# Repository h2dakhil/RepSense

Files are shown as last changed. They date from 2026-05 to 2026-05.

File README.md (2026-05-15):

# Wrist Fitness Tracker — Custom PCB

A wrist-mounted, watch-form wearable that detects and counts gym exercise reps in real time using an IMU and sensor fusion. Built around a circular 42 mm custom PCB designed for low power, low cost, and size-constrained wearable use.

Inspired by the Apple Watch workout detection feature but built from scratch — custom hardware, custom firmware, no cloud dependency.

---

## Overview

The device sits on the wrist like a watch. It reads 6-axis motion data from an IMU, runs an Extended Kalman Filter (EKF) to fuse accelerometer and gyroscope data into a clean orientation estimate, and uses that to detect and count repetitions for exercises including:

- Bicep curl
- Shoulder press
- Bench press
- Lateral raise
- Squat
- Deadlift
- Overhead press

Rep count and exercise type are displayed in real time on a small OLED screen. The entire signal processing pipeline runs on-device with no wireless transmission required in v1.

---

## Hardware

### System block diagram
Screenshot 2026-05-14 at 12 40 06 PM

### MCU — nRF52840 QIAA QFN73

Nordic's nRF52840 was selected because it satisfies every constraint in a single chip with no external LDO required:

- Cortex-M4F at 64 MHz with hardware floating point — needed for EKF math
- Native USB (D+/D−) — drag-and-drop UF2 firmware flashing, no UART bridge chip
- BLE 5.0 built in — phone integration ready for v2 with no extra hardware
- Internal DC-DC converter (DCDCEN0) — steps VDDH down to 3.3V internally, powers entire board via EXTSUPPLY rail
- 1.5 µA deep sleep with wake-on-interrupt — critical for wearable battery life
- VDDH accepts up to 5.5V — direct PMIC output connection, no external LDO needed
- Same chip as the Seeed XIAO nRF52840 Sense used for firmware feasibility validation

**Circuit configuration:** Nordic Config 4 (High Voltage mode, DCDCEN0 enabled, USB enabled, NFC disabled). The PMIC SYS output feeds VDDH directly. The chip's internal REG0 DC-DC produces a stable 3.3V on VDD which is exposed as the board's entire 3.3V supply rail via EXTSUPPLY. One 10 µH inductor on DCCH is the only passive required for this configuration.

**Programming:** First-time bootloader flash via SWD using a J-Link EDU Mini and Tag-Connect TC2030-IDC-NL pads on the PCB. After the Adafruit UF2 bootloader is installed, all subsequent firmware updates are drag-and-drop `.uf2` over USB — identical to the Seeed dev board experience.

**Package selection:** QFN48 was considered and rejected. The QFN48 does not expose D+, D−, or VBUS — USB is physically absent. QFN73 is required. The 1 mm size difference per side is irrelevant at 42 mm PCB diameter.

### IMU — LSM6DSVTR

ST's LSM6DSV was selected for its onboard sensor fusion engine and FSM (Finite State Machine) which offload motion processing from the MCU:

- 6-axis: 3-axis accelerometer (±2 to ±16 g) + 3-axis gyroscope (up to 4000 dps)
- Onboard sensor fusion reduces MCU interrupt load
- Programmable FSM enables gesture and motion pattern detection in hardware
- Large FIFO for buffered data collection, reducing MCU wake frequency
- Low power always-on mode for wrist-raise and motion-triggered wake
- I2C interface, address 0x6A (SA0 pulled to GND)
- INT1 routed to P1.06 — configured as wake-on-motion interrupt

INT1 is the key to efficient battery use. The nRF52840 sleeps at 1.5 µA. When the IMU detects motion above a threshold it pulls INT1 high, waking the MCU instantly. The MCU only runs the rep counting pipeline while the user is actively moving. Between sets and between sessions the system is effectively off.

**I2C pin assignment:** SDA → P1.04, SCL → P1.05, INT1 → P1.06

### PMIC — BQ24074RGTR

TI's BQ24074 handles charging and system power path in a single 3×3 mm QFN:

- Dynamic Power Path Management (DPPM) — simultaneously powers system and charges battery from USB, reducing battery charge/discharge cycles
- USB500 mode selected (EN1 high, EN2 low) — 500 mA input limit, leaves ~400 mA headroom for system after 100 mA charge current
- Charge current set to 100 mA (0.5C for 200 mAh cell) via 9 kΩ ISET resistor
- Input range 4.35–10.5V — compatible with USB 5V
- OVP, thermal regulation, reverse current, and short-circuit protection built in
- TS pin tied to 10 kΩ to GND — battery has no NTC thermistor, this prevents false thermal fault

### Display

0.91" SSD1306 OLED, 128×32 monochrome, I2C address 0x78. Shares I2C bus with IMU — no address conflict. Max 30 mA. Soldered directly to 4× 2.54 mm PTH pads on PCB. Onboard module pullup resistors (4.7 kΩ) serve the entire I2C bus.

### Battery

302035 LiPo, 3.7V nominal, 200 mAh, JST-PH 2 mm 2-pin. Dimensions 36×20×3 mm. Includes onboard protection PCB (OVP, overdischarge, short circuit). Charge current 100 mA (0.5C).

Battery voltage monitored via 1 MΩ/1 MΩ resistor divider to nRF52840 AIN pin for on-screen battery percentage.

---

## Power budget

Design target: low enough average current draw to sustain multi-hour gym sessions on a 200 mAh cell.

### Active current draw (during rep counting)

| Component | Current | Notes |
|---|---|---|
| nRF52840 (active, no BLE) | ~5 mA | Cortex-M4 running EKF + display update |
| LSM6DSV IMU | ~0.35 mA | 3.3V estimated from 0.65 mA at 1.8V |
| OLED display | ~20 mA | Typical for 128×32 at moderate brightness |
| PMIC quiescent | ~0.05 mA | BQ24074 Iq |
| Resistor divider | ~0.002 mA | 2.1 µA, negligible |
| **Total active** | **~25.4 mA** | |

### Sleep current (between sets / idle)

| Component | Current | Notes |
|---|---|---|
| nRF52840 (System ON, wake on RTC) | 1.5 µA | Nordic spec, no RAM retention |
| LSM6DSV (low power accel only) | ~25 µA | Motion detection active, waiting for INT1 |
| OLED display (off) | ~5 µA | Controller standby |
| **Total sleep** | **~32 µA** | |

### Runtime estimate

Assuming a typical 1-hour gym session: 20 minutes active (rep counting) + 40 minutes rest (sleep between sets):

```
Active:  20 min × 25.4 mA  = 508 mAh-min
Sleep:   40 min × 0.032 mA = 1.28 mAh-min
Total:   509 mAh-min / 60  = ~8.5 mAh per session
```

On a 200 mAh cell (usable ~160 mAh accounting for LDO dropout margin):

```
160 mAh / 8.5 mAh per session ≈ ~18 full gym sessions per charge
```

For all-day wear with occasional active periods, sleep current dominates — 32 µA into 200 mAh gives over 250 days of idle standby. In practice charge weekly.

### Battery monitoring

Resistor divider (1 MΩ / 1 MΩ) scales VBAT to half voltage at the ADC pin:

| Battery state | VBAT | AIN voltage | 12-bit ADC count |
|---|---|---|---|
| Full | 4.20 V | 2.10 V | 2606 |
| 75% | 3.90 V | 1.95 V | 2420 |
| 50% | 3.70 V | 1.85 V | 2296 |
| 25% | 3.50 V | 1.75 V | 2172 |
| Low | 3.20 V | 1.60 V | 1986 |

Firmware reverse calculation: `VBAT = ADC_count × 6.6 / 4096`

Divider quiescent drain: 2.1 µA — equivalent to 5.4 years of drain on this cell. Negligible.

---

## Firmware architecture

### Sensing pipeline

```
IMU (6-axis raw) → EKF sensor fusion → orientation estimate
                                              │
                                    rep detection algorithm
                                              │
                                    exercise classifier (heuristic v1)
                                              │
                                       display update
```

### Extended Kalman Filter (EKF)

Raw accelerometer and gyroscope data are fused using an EKF:

- **Prediction step:** gyroscope data integrates orientation forward in time — fast but drifts
- **Correction step:** accelerometer gravity vector corrects the drift — slow but absolute
- **Output:** clean, drift-free quaternion orientation estimate

On a wrist-mounted IMU, gravity rotates in the body frame throughout each rep. This rotation is both the challenge (it confounds raw accelerometer rep detection) and the signal (it gives the EKF its correction input). The EKF output removes gravity ambiguity and produces a clean tilt signal that reps appear as clear periodic waves in.

The nRF52840 Cortex-M4F with hardware floating point handles EKF math at >500 Hz comfortably.

### Rep detection

Per rep, the following features are extracted from the EKF orientation output:

- Dominant motion axis (principal direction of angular change)
- Range of motion in degrees
- Rep duration
- Peak angular velocity
- Zero-crossing frequency

**v1 — Heuristic classifier:** if/else rules on extracted features. Fast, interpretable, no training data required. Handles 5–8 distinct exercises reliably.

**v2 — TinyML:** TensorFlow Lite Micro CNN/MLP on rep window. Better generalisation across users and subtle exercise variations. Planned once v1 heuristics are validated.

### Exercise detection logic

Each exercise has a distinct wrist motion signature:

| Exercise | Primary axis | Motion signature |
|---|---|---|
| Bicep curl | Pitch (wrist rotates forward) | Large pitch swing, ~120° ROM, 1–2 s period |
| Shoulder press | Vertical translation dominant | High Z accel, moderate pitch, pressing pattern |
| Bench press | Elbow extension dominant | Moderate pitch, low ROM, bilateral pattern |
| Lateral raise | Roll (arm lifts sideways) | Large roll swing, ~90° ROM |
| Squat | Body pitch with knee flexion | Slow deep pitch oscillation, ~3–4 s |
| Deadlift | Hip hinge dominant | Large pitch, high peak accel on concentric |
| Overhead press | Similar to shoulder press | Higher ROM, full elbow extension signature |

The classifier reads the dominant axis, ROM range, and rep cadence. Most exercises are distinct enough that a threshold-based decision tree separates them reliably. Exercises with similar signatures (shoulder press vs overhead press) are disambiguated by ROM magnitude.

### Wake-on-motion

IMU INT1 configured as motion-detect interrupt → nRF52840 GPIO wakeup. MCU stays in System ON sleep (1.5 µA) until motion above threshold detected. Eliminates polling entirely.

---

## PCB

- **Form factor:** circular, 42 mm diameter
- **Layers:** 2
- **Manufacturer:** JLCPCB (fabrication + assembly)
- **Assembly:** JLCPCB SMT — nRF52840 QFN73, BQ24074 QFN16, LSM6DSV LGA14 all assembled
- **Programming interface:** Tag-Connect TC2030-IDC-NL pads (no legs, flush with PCB surface)
- **Reset:** SMD momentary button, RESET pin → GND, 10 kΩ pullup, 100 nF filter cap
- **Antenna:** unpopulated in v1 (BLE not enabled). RF matching network footprints retained DNP for v2 population without board respin
- **Crystal:** 32 MHz SMD2016 (YXC X2016 32MKB4SI, LCSC C718072) mandatory main clock. 32.768 kHz RTC crystal footprint DNP for v2

---

## Estimated unit cost

Based on JLCPCB pricing at low volume (5 units):

| Item | Est. cost (USD) |
|---|---|
| PCB fabrication (5× circular 42 mm, 2-layer) | ~$2.00/unit |
| nRF52840 QIAA QFN73 (LCSC C190794) | ~$6.50 |
| LSM6DSVTR IMU | ~$3.50 |
| BQ24074RGTR PMIC | ~$2.50 |
| 32 MHz crystal | ~$0.10 |
| 10 µH inductor (DCCH) | ~$0.15 |
| Passives (caps, resistors, ESD) | ~$0.50 |
| USB-C connector | ~$0.30 |
| JST-PH battery connector | ~$0.20 |
| OLED display module | ~$3.00 |
| LiPo 302035 200 mAh | ~$3.00 |
| JLCPCB SMT assembly fee (est.) | ~$8.00 |
| **Total per unit (5-unit run)** | **~$29.75** |

Cost drops significantly at higher volumes — MCU and PMIC pricing improves at 50+ units and assembly amortises across more boards.

---

## Feasibility validation

Before committing to the custom PCB, the full sensing pipeline was prototyped and validated on a **Seeed XIAO nRF52840 Sense** development board. This board uses the same nRF52840 MCU and includes an onboard LSM6DS3 IMU (predecessor to the LSM6DSV used in the final design).

Validation confirmed:
- IMU data acquisition over I2C at the required sample rate
- Raw accelerometer and gyroscope signal quality for rep detection
- Wrist-mounted motion signatures are clearly periodic and distinguishable per exercise
- nRF52840 toolchain (Adafruit nRF52 Arduino framework) workflow — compile, UF2 drag-and-drop flash, serial monitor
- EKF algorithm correctness on real motion data before hardware commitment

The custom PCB is a direct hardware consolidation of the validated dev board pipeline — same MCU, same firmware framework, same IMU family — into a circular wearable form factor.

---

## Repository structure

```
/firmware          nRF52840 Arduino/PlatformIO firmware
/hardware          KiCad schematic and PCB layout files
/docs              design notes, component datasheets, calculations
/data              CSV motion logs from feasibility phase
README.md
```

---

## Roadmap

| Version | Status | Description |
|---|---|---|
| v1 | In progress | Custom PCB, heuristic rep counter, OLED display, 5 exercises |
| v2 | Planned | BLE to iPhone, TinyML classifier, 10+ exercises, OTA firmware updates |
| v3 | Future | Custom enclosure, production-ready assembly, refined form factor |

---

## Design constraints summary

| Constraint | Approach |
|---|---|
| Size | 42 mm circular PCB, no external LDO, all ICs QFN/LGA |
| Low power | nRF52840 1.5 µA sleep, IMU wake-on-motion INT1, display off between updates |
| Low cost | ~$30/unit at 5 units, ~$18 at volume; single-sided JLCPCB assembly |
| Programmability | Native USB UF2 after one-time SWD bootloader flash |
| Sensor accuracy | EKF fusion eliminates gyro drift and gravity confusion on raw accel |

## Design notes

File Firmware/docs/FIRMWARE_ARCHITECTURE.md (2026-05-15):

# RepSense Firmware Architecture

Firmware for a wrist-mounted fitness tracker built on the Nordic nRF52840 with an
ST LSM6DSV 6-DoF IMU and a 0.91" SSD1306 OLED. The firmware sleeps under 35 µA,
wakes on motion, fuses IMU data through a quaternion EKF, counts reps via
peak/zero-crossing detection on the dominant axis, and classifies the exercise
with a heuristic decision tree.

---

## Module map

```
┌──────────────────────────────────────────────────────────────────┐
│                            main.cpp                              │
│      BOOT → SLEEP → ACTIVE → DISPLAY_UPDATE → SLEEP              │
└───────┬──────────────┬─────────────┬────────────┬────────────────┘
        │              │             │            │
   ┌────▼────┐    ┌────▼────┐   ┌────▼─────┐  ┌───▼──────┐
   │  power  │    │   imu   │   │   ekf    │  │ battery  │
   └─────────┘    └────┬────┘   └────┬─────┘  └──────────┘
                       │             │
                       ▼             ▼
                  ┌────────────────────────┐
                  │     rep_detector       │
                  └───────────┬────────────┘
                              ▼
                  ┌────────────────────────┐
                  │ exercise_classifier    │
                  └───────────┬────────────┘
                              ▼
                          ┌────────┐
                          │display │
                          └────────┘
```

---

## Module reference

### `config.h`
Single source of truth for pin assignments, I2C addresses, ADC scaling,
EKF noise covariances, rep-detector thresholds, per-exercise classifier
thresholds, and state-machine timing. No magic numbers may appear in
the `.cpp` files; everything is a named constant here.

### `power.h / power.cpp`
- **Responsibilities:** enable nRF52840 DC-DC converter (`NRF_POWER->DCDCEN = 1`),
  disable unused peripherals (UART0/UARTE0, SPIM0..2, PWM0..2) to hit the
  <35 µA sleep budget, manage System ON sleep via `__WFE`, and latch the
  IMU wake interrupt for the state machine.
- **Inputs:** wake ISR notifications from `imu`.
- **Outputs:** `wakeRequested()` flag consumed by the main loop.
- **Connections:** called by `main.cpp` on boot and at sleep/wake transitions.

### `imu.h / imu.cpp`
- **Responsibilities:** LSM6DSV init over I2C @ 400 kHz, WHO_AM_I verification
  (expects `0x70`), accel `±8 g` / gyro `±2000 dps` at 208 Hz ODR in
  high-performance mode, motion-detect wake configuration via
  `WAKE_UP_THS` / `WAKE_UP_DUR` / `MD1_CFG`, INT1 routed to P1.06 with a
  rising-edge attachInterrupt.
- **Inputs:** I2C bus, INT1 pin.
- **Outputs:** `imu::read()` returns a 6-axis SI-units sample plus an `ok` flag.
- **Connections:** consumed by `ekf` and `rep_detector` indirectly via `main.cpp`.
  Bus errors are logged under `#ifdef DEBUG` and degraded gracefully — the EKF
  step is skipped for that tick.

### `ekf.h / ekf.cpp`
- **Responsibilities:** quaternion-based EKF, the core algorithm.
  - **State:** `q = [q0,q1,q2,q3]` (body → world unit quaternion).
  - **Predict:** `F = I + 0.5·Ω(ω)·dt`, `q⁻ = F·q`, `P⁻ = F·P·Fᵀ + Q`.
  - **Update:** measurement `h(q)` is the predicted gravity direction in
    body coordinates; analytical 3×4 Jacobian `H = ∂h/∂q`; innovation
    `y = ẑ − h(q)`; Kalman gain `K = P·Hᵀ·(H·P·Hᵀ + R)⁻¹`;
    `q⁺ = q + K·y` (re-normalised); `P⁺ = (I − K·H)·P`.
  - **Adaptive R:** `R` inflates with `(|a| − g)²` to down-weight the accel
    update during transient limb motion.
  - **Outputs:** `getRoll/Pitch/Yaw` in degrees, `getQuaternion`, and a
    gravity-removed linear acceleration vector for the rep detector.
- **Tunables:** `EKF_Q_GYRO`, `EKF_R_ACCEL`, `EKF_P_INIT` in `config.h`.
- **Notes:** all single-precision (`float`) — Cortex-M4F has a hardware FPU
  for single-precision only; using `double` would silently fall back to
  software emulation and miss the 200 Hz deadline.

### `rep_detector.h / rep_detector.cpp`
- **Responsibilities:** turn streaming EKF output into discrete reps.
  - Rolling 64-sample window of pitch/roll/yaw for dominant-axis RMS selection.
  - First-order high-pass filter (`y = α·(y_prev + x − x_prev)`) removes the
    user's neutral-wrist DC offset so signals oscillate about zero.
  - Zero-crossing state machine with hysteresis (`REP_ZERO_HYSTERESIS`):
    a `Positive → Negative → Positive` traversal commits one rep.
  - Per-rep validation: duration ∈ [0.4 s, 6 s] and ROM ≥ 25°.
  - On commit, snapshots `RepFeatures` (ROM, peak |ω|, peak |a|, RMS
    per axis, duration, timestamp).
- **Inputs:** Euler angles + gyro + linear-accel from `ekf`.
- **Outputs:** `getRepCount`, `getLastRepFeatures`, and the `process()`
  return flag.

### `exercise_classifier.h / exercise_classifier.cpp`
- **Responsibilities:** heuristic decision tree mapping `RepFeatures` →
  `ExerciseType`. Ordered most-unique signature first:
  Deadlift → Squat → Lateral Raise → Row → Overhead Press → Shoulder Press →
  Bicep Curl → Bench Press → Tricep Pushdown.
- **Confidence:** requires `CLASSIFIER_CONFIRM_REPS` (= 3) consecutive
  matching reps before committing a label. Single-rep noise can't latch
  the wrong exercise on the display.
- **Inputs:** `RepFeatures` struct from `rep_detector`.
- **Outputs:** `Result { ExerciseType, bool confident }` and a stable
  `getCommitted()` accessor for the display.

### `battery.h / battery.cpp`
- **Responsibilities:** read AIN via the SAADC (`AR_VDD4` reference, 12-bit
  resolution), convert via `VBAT = ADC × 6.6 / 4096`, then map voltage →
  percent through a piecewise-linear interpolation of an 8-point LiPo
  discharge curve. Sampled at most once per 30 s.
- **Inputs:** AIN voltage at the battery divider.
- **Outputs:** `getBatteryVoltage()`, `getBatteryPercent()`.

### `display.h / display.cpp`
- **Responsibilities:** SSD1306 driver wrapping Adafruit_GFX/SSD1306.
  - **Boot screen:** project name + version for `BOOT_SCREEN_MS`.
  - **Active screen:** exercise name (top-left), rep count (centre,
    size 3), battery icon (top-right). Partial redraws — each region is
    only repainted when its underlying value changes.
  - **Rest screen:** "REST" + last set summary.
  - **Sleep:** `SSD1306_DISPLAYOFF` to drop panel current to standby.
- **Inputs:** committed exercise label, rep count, battery percent.
- **Outputs:** I2C traffic to address `0x3C`.

### `main.cpp`
- **Responsibilities:** the state machine.
  - **BOOT:** init power → display → IMU → battery → EKF → detector →
    classifier; show splash; arm wake; → SLEEP.
  - **SLEEP:** WFE until INT1; clear flags; → ACTIVE.
  - **ACTIVE:** 200 Hz paced loop; IMU read → EKF step → rep_detector →
    classifier; partial repaint on commit. If `IDLE_BEFORE_SLEEP_MS`
    elapses without motion → SLEEP.
  - **DISPLAY_UPDATE:** single-shot OLED repaint after a confirmed rep,
    then back to ACTIVE.

---

## Data flow (one active tick)

```
IMU.read()  → 6 floats (a, ω)
   │
   ▼
ekf::step()   → q, roll/pitch/yaw, linAccel
   │
   ▼
rep_detector::process()  → bool repCommitted, RepFeatures (on commit)
   │ (if commit)
   ▼
classifier::classify()   → Result { type, confident }
   │
   ▼
display::showActive(type, repCount, batteryPct)
```

## Power budget (target)

| Component | Current |
|---|---|
| nRF52840 System ON sleep | ~1.5 µA |
| LSM6DSV activity-detect  | ~25 µA |
| SSD1306 panel off | ~5 µA |
| **Total sleep** | **< 35 µA**  |

## Build

```
pio run -e adafruit_feather_nrf52840
pio run -e adafruit_feather_nrf52840 -t upload
pio device monitor
```

Release builds: drop `-DDEBUG` from `platformio.ini` to compile out all
Serial logging and avoid the UART power cost.

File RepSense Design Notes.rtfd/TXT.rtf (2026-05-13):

Design optimizations
The design of this pcb is optimized for low power, size, and progammability.
Main MCU - NRF52840
The nRF52840 was chosen because it hits every requirement of this project in a single chip. It has a Cortex-M4 with hardware floating point which is needed for the EKF sensor fusion math. It has native USB built in so no bridge chip is needed for programming. It has BLE 5.0 built in for the future phone integration without adding any external module. Its deep sleep current is around 1.5µA which is critical for a wearable running on a small LiPo. It also has an internal DC-DC converter that can be enabled in firmware to improve power efficiency further. The nRF52840 is the same chip used in the Seeed XIAO dev board already validated for this project, meaning the firmware toolchain, libraries, and IMU drivers are already familiar. No other single chip combines low power, native USB, BLE, and sufficient processing headroom for motion algorithms at this price point and package size.

The chip also has internal regulator; it can accept up to 5V5 on its VDDH pin and internally step down to 3V3 for internal use and external power. So no LDO is actually needed on this board because of it.

I went with the QFN-73 variant even though all 73 pins weren’t needed (mcu will only support IMU and LCD). The nRF52840 comes in two QFN packages - QFN73 (7x7mm) and QFN48 (6x6mm). The QFN48 was rejected immediately because it has no USB pins - D+, D-, and VBUS are all absent. Since this design relies on USB for drag-and-drop firmware flashing and for detecting when the charger is plugged in, the QFN48 is a hard no regardless of its smaller size. The 1mm size difference on each side is irrelevant on a 42mm PCB anyway. QFN73 it is, LCSC part C190794.

The baseline design was followed by Nordic’s documentation: https://docs.nordicsemi.com/bundle/ps_nrf52840/page/pin.html
For the QFN73 there are 7 different configurations to follow based on your circuitry. I followed the one that allows features as:
Selected: Config 4 (QIAA aQFN73)

VDDH = Battery/Ext. regulator (PMIC output) The PMIC output (sourced from either USB or LiPo depending on what's plugged in) feeds directly into VDDH. This puts the chip in High Voltage mode, meaning the internal REG0 regulator handles stepping the input voltage down internally. No external LDO required.
VDD = N/A In High Voltage mode VDD is an output, not an input. The internal REG0 regulator produces the regulated 3.3V on this pin. Left unconnected from any external supply.
EXTSUPPLY = Yes The regulated 3.3V on VDD is exposed to power external components — specifically the LSM6DSV IMU (0.65mA max) and the display.
DCDCEN0 must be enabled for this to work reliably given the current draw of the display. DCDCEN0 = Yes Enables the internal DC-DC switching converter for REG0 instead of the internal LDO. This raises the maximum current the chip can supply externally beyond the 25mA LDO limit, and is more efficient — it draws less from the battery for the same output. Requires one external 10µH inductor on the DCCH pin. This is the only extra passive component this config adds.
DCDCEN1 = No The REG1 DC-DC converter (which powers the chip core from VDD) is left disabled for v1 simplicity. REG1 runs as internal LDO instead. Can be enabled in a future revision for further efficiency gains.
USB = Yes D+ and D- are wired to the USB-C connector for firmware flashing.
VBUS is connected to the USB-C 5V line so the chip can detect when USB is plugged in and trigger the appropriate power and charging events in firmware. NFC = No NFC pins left unconnected. Not used in v1 or v2.

AD2 VBUS - It's just a sense/detection pin with its own isolated internal regulator. You wire it to VBUS on the USB-C connector (5V)
AD14 VDD - in Config 4 VDD is an output. It's your 3.3V rail that goes to: IMU (VDD pin on LSM6DSV) Display (VCC pin) Any other 3.3V peripherals And it also has decoupling caps to GND on each VDD pin of the nRF52840 itself — the datasheet specifies 100nF on each one, placed as close to the pin as physically possible on the PCB. So on schematic VDD is just a net label "3V3" that connects to everything that needs 3.3V.
SWD Debugging
The J-Link and Tag-Connect are two separate physical things that connect together in a chain: Mac → USB cable → J-Link EDU Mini → J-Link's ribbon cable → Tag-Connect adapter → Tag-Connect cable → PCB pads
ANT NOT BEING USED.

DN-004 — 32.768kHz RTC Crystal (XL1/XL2) The nRF52840 has two crystal inputs — a mandatory 32MHz main clock on XC1/XC2 and an optional 32.768kHz low-frequency crystal on XL1/XL2 used for RTC timekeeping and accurate BLE low-power advertising. For v1 the 32.768kHz crystal is omitted. This device has no timekeeping requirement and BLE is not implemented in v1, so the internal RC oscillator is sufficient for basic sleep/wake timing. XL1 and XL2 are left as no-connect in the schematic. The crystal footprint will be added as DNP on the PCB for potential population in v2 when BLE and low-power sleep modes are implemented.

NFC1/2 pins - antenna loop not being used
In KiCad: put no-connect flags on NFC1 and NFC2, done
In firmware: one UICR register write to disable NFC mode, or use a framework that does it for you

Battery power path IC measurement

IMU
3. IMU
LSM6DSVTR (https://www.lcsc.com/product-detail/C5267399.html?s_z=n_q_imu)

Justification:
- ST ecosystem + supported by Arduino libraries
- 6 axis IMU (3-axis accelerometer, 3-axis gyroscope) with digital I2C/SPI interface
-low power consumption
- integrated sensor fusion and programmable finite state machine (FSM) , reducing MCU processing load and enabling more advanced motion features without firmware complexity
- high performance, widely used so lots more documentation
- configurable ranges (2-16g acule, up to 4000dps gyro) to support low noise precision sensing, high-dynamic applications
- low-power “always on” operation
- large FIFO - enables buffering of motion data, reducing MCU interrupt load and allowing more efficient data handling

Power:
1.7 - 3.6V, 1.8V typical. I am powering it via 3V3.
0.65mA active in high-performance mode (accel + gyro) for 1.8V.
Estimated current for 3.3V:
If P = 1.8 * 0.65 = 1.17mW and P remains same regardless of 1.8V or 3V3,
I_3V3 = 1.17/3.3V = 0.35
Current is estimated to 0.35mA with 3.3V

Address: 0x6A (SA0 = 0) or 0x6B(SA0 = 1)

Design notes:
Datasheet mentions 3 possible interface connections. Mode 1 was selected which is MCU communicating to IMU via I2C. Other modes are not relevant as they treat the IMU as a master

SD0/SA0 - Connected to GND to set 0x6A address
CS - pulled to 3V3 - data sheet does not state requirement of a resistor , cant find out if there is an internal pull-up
SDX/SCX - no use case in mode 1 - option was either connect to VDD_IO (HIGH) or GND (LOW). Pulled to GND.
INT1/INT2 - programmable interrupt. INT1 routed to GPIO for ability to implement it in firmware. INT2 left floating.
this will be used for the LSM6DSV can be configured to generate an interrupt when motion is detected, waking the nRF52840 from deep sleep. This is critical for battery life on a wearable.
The flow would be: Device idle → nRF52840 in deep sleep (1.5µA), IMU in low power mode User starts moving → IMU detects motion → pulls INT1 high → wakes nRF52840 instantly nRF52840 starts sampling and counting reps User stops → back to sleep Without INT1 connected you'd have to poll the IMU constantly which kills battery life. With it connected you get essentially free wake-on-motion. Configure it as an input with interrupt in firmware. Connected to P1.06
SDO_AUX/OCS_AUX - not a feature In mode 1; left floating as per data sheet
Display
HS91L02W2C01 (Shenzhen Hansheng, 0.91" OLED)
SSD1306 controller, 128×32 monochrome white OLED, I2C interface.
Fixed I2C address 0x78 (per datasheet pin definition, page 7).
Shares I2C bus with LSM6DSV IMU (0x6A) on P1.04 (SDA) and P1.05 (SCL) — no address conflict.
VCC 3.3V–3.5V (per datasheet absolute max ratings, page 9) supplied from nRF52840 EXTSUPPLY rail.
VDD logic supply 1.65–3.3V, also 3.3V. Connected by soldering display module directly onto 4 × 2.54mm PTH pads on PCB (GND, VCC, SCL, SDA). Male header pins inserted through display module holes, soldered, excess clipped flush. ‘Max 29mA

NOTE — Layout: Reserve a 38×12mm keep-out zone on PCB surface matching display module body. Draw courtyard in KiCad covering full module footprint. Place no tall components within this zone as display sits directly on top. Position the 4 PTH pads centered on the board to align display symmetrically. Pads are 2.54mm pitch inline.
I2C BUS PULLUP RESISTORS
SDA (P1.04) and SCL (P1.05) pullups to 3.3V are DNP. I2C bus pullups are provided by the onboard 4.7K resistors on the HS91L02W2C01 display module (confirmed from module schematic, page 8, R6 and R7).
These serve the entire bus including the LSM6DSV IMU.
Footprints retained on PCB for flexibility in case display is replaced with a module lacking onboard pullups.
Distance from pullup to MCU is not a concern at this PCB scale — total trace length across the entire bus is under 30mm with only two devices, making capacitive effects negligible.
4.7kΩ is sufficient to meet the 300ns maximum rise time specified in the display datasheet (page 11, AC characteristics).
Battery
The battery chosen is DC 3.7V 200mAh 302035 LiPo, 200mAh rated; max 0.2A continuous current

Max continuous discharge 200mA (1C). Dimensions 36×20×3mm.
Connector: JST PH 2mm pitch, 2-pin pigtail — PCB receptacle LCSC C295747.
Charge current set to 100mA (0.5C) via BQ24074 ISET resistor. Battery voltage monitored via 1MΩ/1MΩ divider to nRF52840 AIN pin; 4.2V = 100%, 3.0V = 0%. Cell includes onboard protection PCB (OVP, overdischarge, short circuit) — safety net only, PMIC is primary protection.

ISET. From datasheet eqn 2:
¬
I will use a 8.9K from ISET to GND 1% tolerance . Used 9K because of stock.

TS (pin 1)
Your battery has no NTC thermistor. Per datasheet page 25, for applications not using TS monitoring connect a 10kΩ resistor from TS to GND. This holds the pin at a valid voltage so the charger doesn't think there's a temperature fault and suspend charging. That's it, one resistor to GND, done.

PMIC
BQ24074 - USB charger with smart power path management
Selectable 100mA and 500mA max input current, 100mA max current limit ensures compliance to USB-IF standard

From the datasheet page 6, the EN1/EN2 pins offer four modes: both low gives USB100 (100mA input limit),
EN1 high EN2 low gives USB500 (500mA input limit),
EN1 low EN2 high gives resistor-programmable mode via ILIM pin, and both high puts the device in standby/suspend.
USB100 was rejected immediately because with a 100mA input limit and 100mA charge current there is zero headroom left for the system load — the nRF52840 alone draws more than that when active. Resistor-programmable and standby are unnecessary complexity for v1.
USB500 was selected (EN1 high, EN2 low) giving a 500mA input limit from the USB port, which allows 100mA to charge the battery while leaving ~400mA available for the system load consisting of the MCU, IMU, and display — well within what a standard USB port supplies.
BQ24074
The bq24074 is a linear Li-Ion charger and power-path management IC from TI's bq2407x family. Its Dynamic Power Path Management (DPPM) simultaneously powers the system and charges the battery from the same input, reducing unnecessary battery cycles and allowing operation with a depleted cell. Charge current, input current limit, and termination threshold are all resistor-programmable. The bq24074 was selected over other family variants for its adjustable termination current (ITERM pin) and wider input voltage range of 4.35–10.5V, accommodating unregulated adapters alongside USB. Onboard protections include OVP, thermal regulation, reverse current blocking, and short-circuit detection, all in a 3×3mm 16-pin QFN.

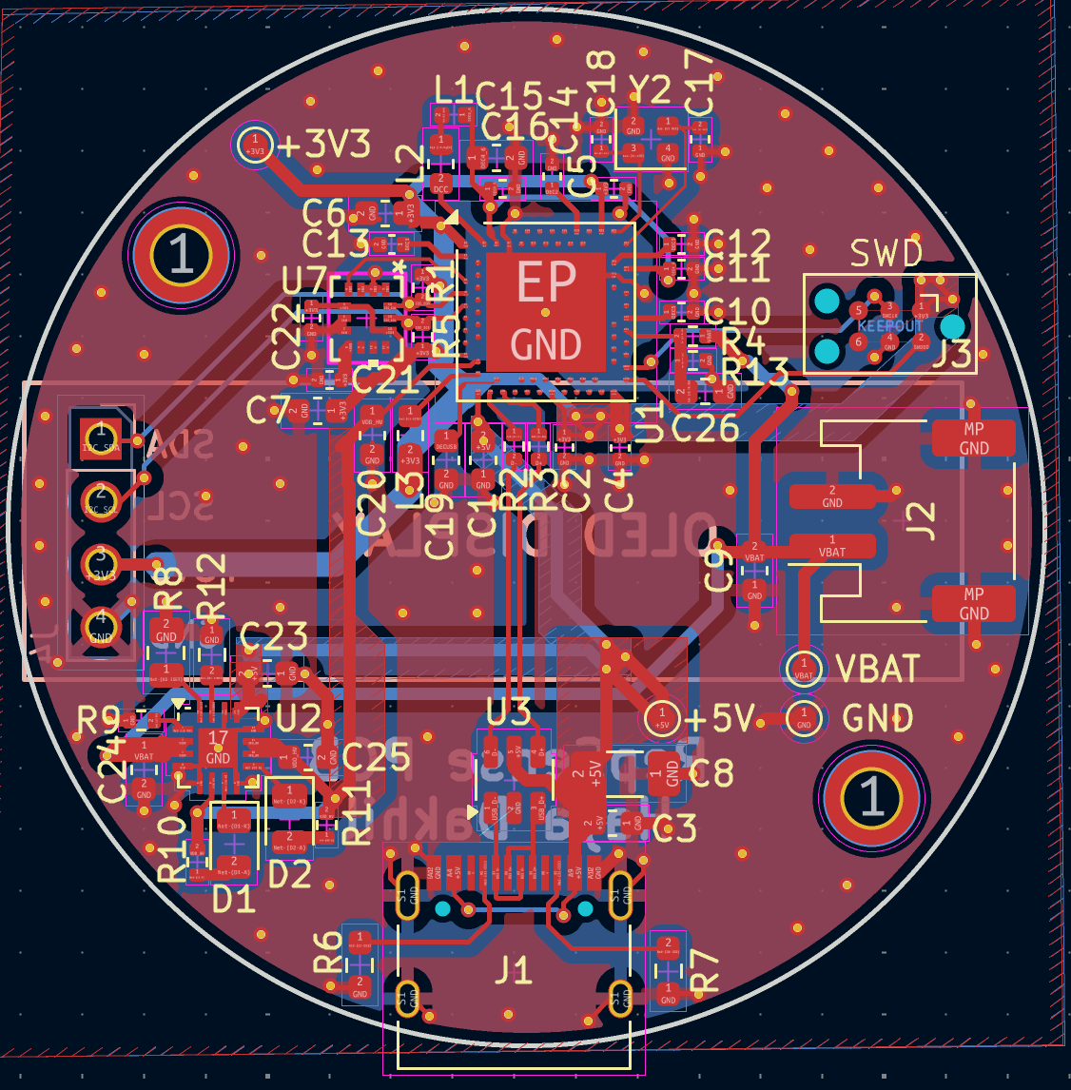
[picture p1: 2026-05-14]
Hardware/PCB/PNGs/Footprint/F.Cu.png

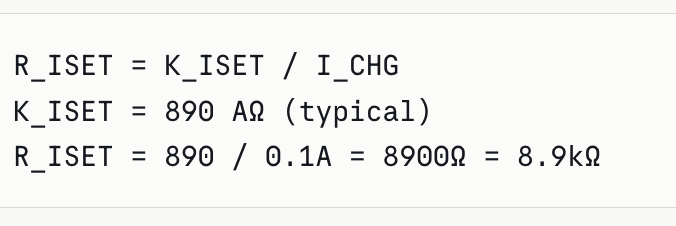
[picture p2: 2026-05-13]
Hardware/PCB/RepSense Design Notes.rtfd/Pasted Graphic.png

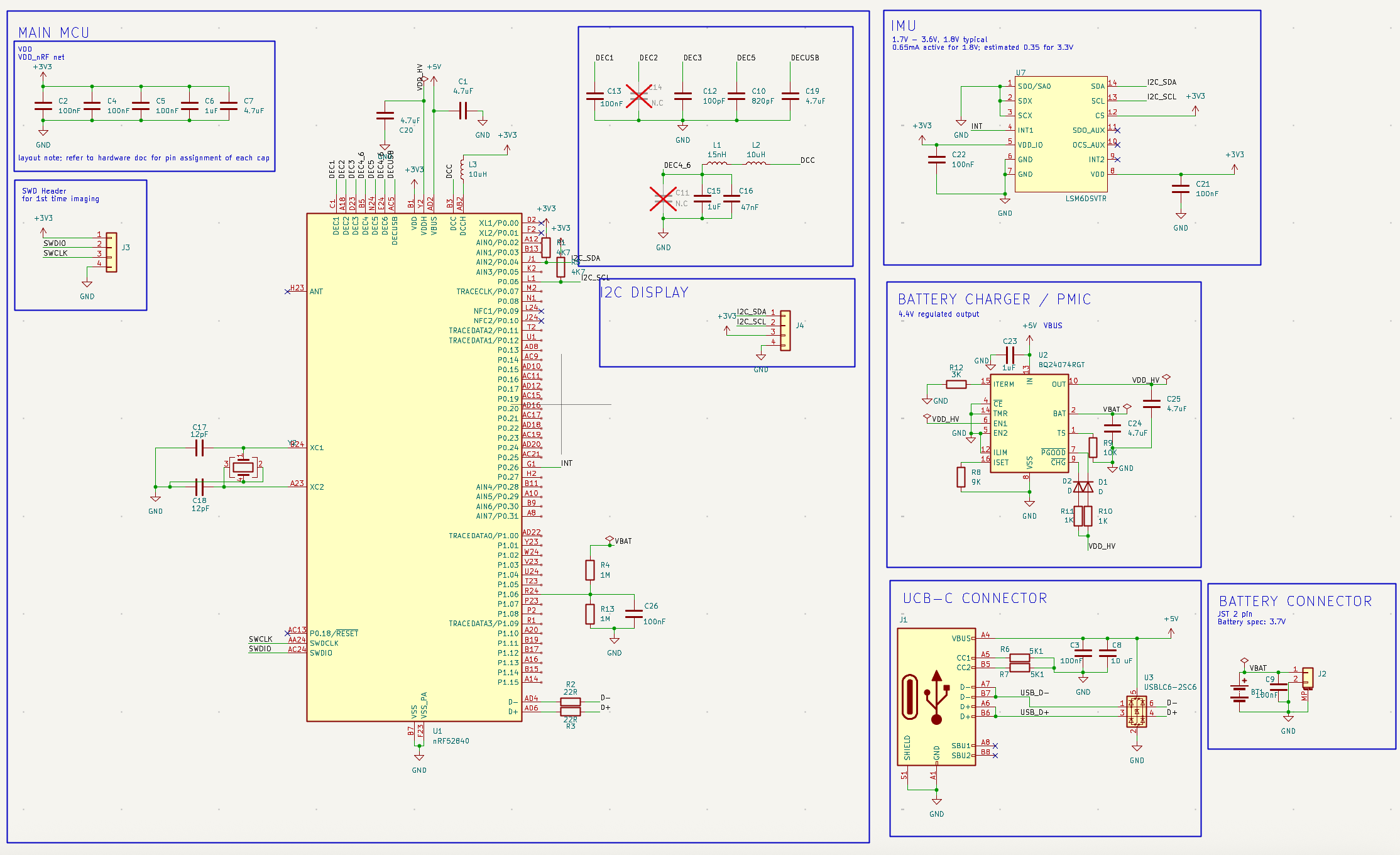
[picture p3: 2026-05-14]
Hardware/PCB/PNGs/Schematic/Schematic.png

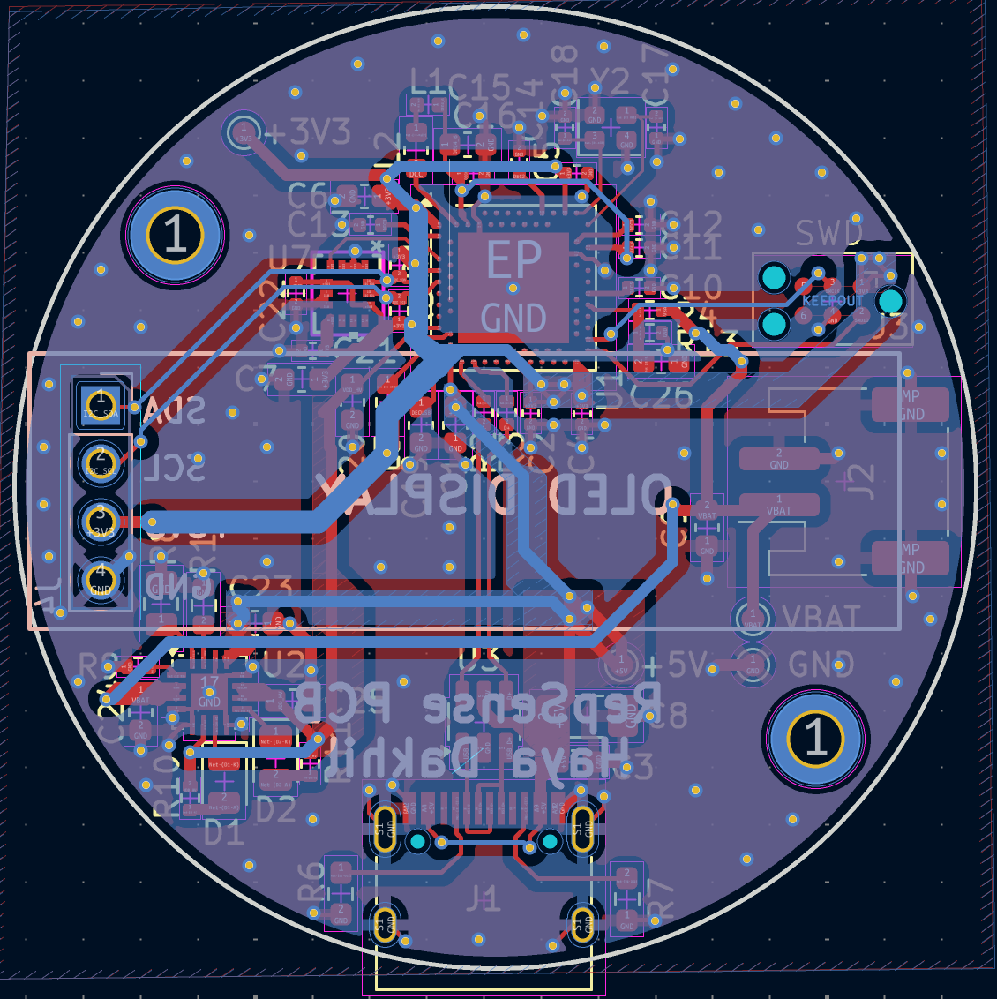
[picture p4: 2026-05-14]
Hardware/PCB/PNGs/Footprint/B.Cu.png

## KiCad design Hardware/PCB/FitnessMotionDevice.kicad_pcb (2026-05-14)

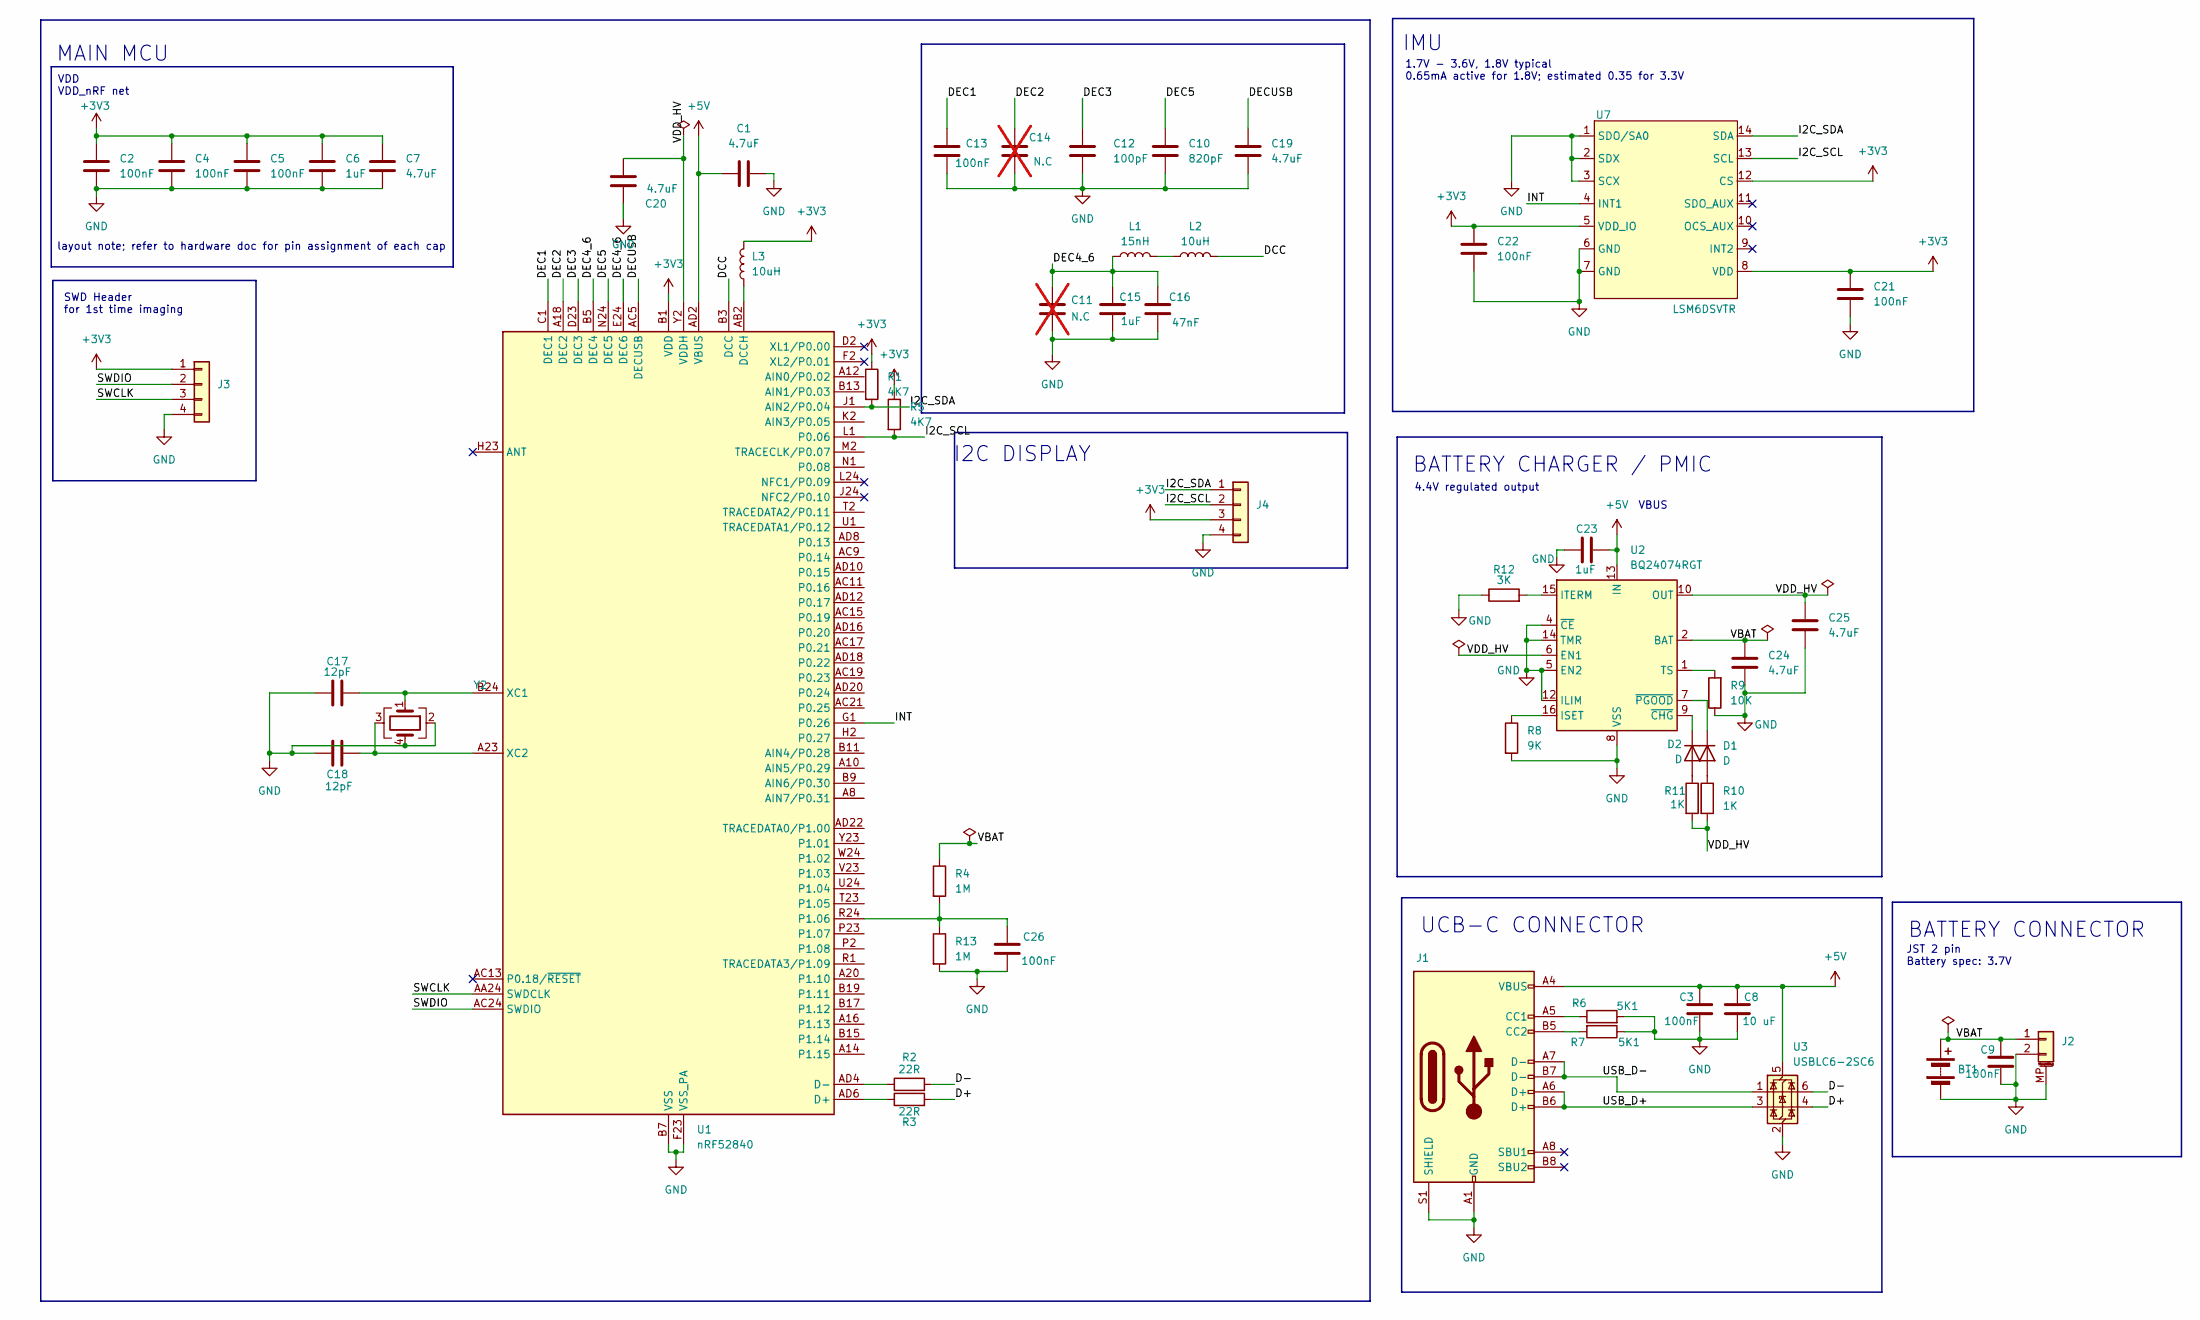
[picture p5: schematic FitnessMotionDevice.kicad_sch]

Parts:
BT1: Battery
C1, C20, C24, C25: 4.7uF; C_0603_1608Metric; LCSC C385034
C2, C4, C5, C21, C22: 100nF; C_0402_1005Metric; LCSC C60474
C3, C9, C26: 100nF; C_0603_1608Metric; LCSC C14663
C6, C23: 1uF; C_0603_1608Metric; LCSC C29936
C7, C19: 4.7uF; C_0603_1608Metric; LCSC C389010
C8: 10 uF; C_1206_3216Metric_Pad1.33x1.80mm_HandSolder; LCSC C89632
C10: 820pF; C_0402_1005Metric; LCSC C726612
C11, C14: N.C; C_0402_1005Metric; not fitted
C12: 100pF; C_0402_1005Metric; LCSC C106200
C13: 100nF; C_0402_1005Metric
C15: 1uF; C_0603_1608Metric
C16: 47nF; C_0402_1005Metric; LCSC C272875
C17, C18: 12pF; C_0402_1005Metric; LCSC C326662
D1, D2: D; LED_0805_2012Metric; LCSC C19171391
J1: USB_C_Receptacle_USB2.0_16P; USB_C_Receptacle_HRO_TYPE-C-31-M-12; LCSC C2765186
J2: Conn_01x02_MountingPin; JST_PH_S2B-PH-SM4-TB_1x02-1MP_P2.00mm_Horizontal; LCSC C295747
J3: Conn_01x04; Tag-Connect_TC2030-IDC-NL_2x03_P1.27mm_Vertical
J4: Conn_01x04; PinHeader_1x04_P2.54mm_Vertical
L1: 15nH; L_0402_1005Metric; LCSC C98055
L2: 10uH; L_0603_1608Metric; LCSC C86083
L3: 10uH; L_0603_1608Metric; LCSC C76798
R1, R5: 4K7; R_0402_1005Metric; LCSC C105871
R2, R3: 22R; R_0402_1005Metric; LCSC C114765
R4, R13: 1M; R_0402_1005Metric; LCSC C138033
R6, R7: 5K1; R_0603_1608Metric_Pad0.98x0.95mm_HandSolder; LCSC C2907044
R8: 9K; R_0805_2012Metric; LCSC C2930212
R9: 10K; R_0402_1005Metric; LCSC C60490
R10, R11: 1K; R_0402_1005Metric; LCSC C106235
R12: 3K; R_0603_1608Metric; LCSC C2907033
U1: nRF52840; Nordic_AQFN-73-1EP_7x7mm_P0.5mm; LCSC C190794
U2: BQ24074RGT; VQFN-16-1EP_3x3mm_P0.5mm_EP1.6x1.6mm; LCSC C54313
U3: USBLC6-2SC6; SOT-23-6; LCSC C7519
U7: LSM6DSVTR; LGA14-L_2P59X3P1X0P5_STM; LCSC C5267399
Y2: Crystal_GND23; Crystal_SMD_2016-4Pin_2.0x1.6mm

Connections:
+3V3: C2.1, C4.1, C5.1, C6.1, C7.1, C21.1, C22.1, J3.1, J4.3, L3.2, R1.1, R5.1, U1.A22 (VDD), U1.AD14 (VDD), U1.AD23 (VDD), U1.B1 (VDD), U1.W1 (VDD), U7.5 (VDD_IO), U7.8 (VDD), U7.12 (CS); also elsewhere on the board
+5V: C1.2, C3.2, C8.2, C23.2, J1.A4 (VBUS), J1.A9 (VBUS), J1.B4 (VBUS), J1.B9 (VBUS), U1.AD2 (VBUS), U2.13 (IN), U3.5 (VBUS); also elsewhere on the board
/D+: R3.2, U3.4 (I/O2)
/D-: R2.2, U3.6 (I/O1)
/DCC: L2.2, U1.B3 (DCC)
/DEC1: C13.1, U1.C1 (DEC1)
/DEC2: C14.1, U1.A18 (DEC2)
/DEC3: C12.1, U1.D23 (DEC3)
/DEC4_6: C11.1, C15.1, C16.1, L1.1, U1.B5 (DEC4), U1.E24 (DEC6)
/DEC5: C10.1, U1.N24 (DEC5)
/DECUSB: C19.1, U1.AC5 (DECUSB)
/I2C_SCL: J4.2, R5.2, U1.L1 (P0.06), U7.13 (SCL)
/I2C_SDA: J4.1, R1.2, U1.J1 (AIN2/P0.04), U7.14 (SDA)
/INT: U1.G1 (P0.26), U7.4 (INT1)
/SWCLK: J3.3, U1.AA24 (SWDCLK)
/SWDIO: J3.2, U1.AC24 (SWDIO)
/USB_D+: J1.A6 (D+), J1.B6 (D+), U3.3 (I/O2)
/USB_D-: J1.A7 (D-), J1.B7 (D-), U3.1 (I/O1)
/VBAT: BT1.1 (+), C9.2, C24.1, J2.1, R4.1, U2.2 (BAT), U2.3 (BAT); also elsewhere on the board
/VDD_HV: C20.1, C25.1, R10.2, R11.2, U1.Y2 (VDDH), U2.6 (EN1), U2.10 (OUT), U2.11 (OUT)
GND: BT1.2 (-), C1.1, C2.2, C3.1, C4.2, C5.2, C6.2, C7.2, C8.1, C9.1, C10.2, C11.2, C12.2, C13.2, C14.2, C15.2, C16.2, C17.1, C18.2, C19.2, C20.2, C21.2, C22.2, C23.1, C24.2, C25.2, C26.1, J1.A1 (GND), J1.A12 (GND), J1.B1 (GND), J1.B12 (GND), J1.S1 (SHIELD), J2.2, J2.MP (MountPin), J3.4, J4.4, R6.2, R7.1, R8.2, R9.1, R12.1, R13.2, U1.B7 (VSS), U1.EP (VSS), U1.F23 (VSS_PA), U2.4 (~CE), U2.5 (EN2), U2.8 (VSS), U2.12 (ILIM), U2.14 (TMR), U2.17 (VSS), U3.2 (GND), U7.1 (SDO/SA0), U7.2 (SDX), U7.3 (SCX), U7.6 (GND), U7.7 (GND), Y2.2, Y2.4; also elsewhere on the board
unnamed: D1.2 (A), R10.1
unnamed: D1.1 (K), U2.7 (~PGOOD)
unnamed: D2.2 (A), R11.1
unnamed: D2.1 (K), U2.9 (~CHG)
unnamed: J1.A5 (CC1), R6.1
unnamed: J1.B5 (CC2), R7.2
unnamed: L1.2, L2.1
unnamed: R3.1, U1.AD6 (D+)
unnamed: R2.1, U1.AD4 (D-)
unnamed: L3.1, U1.AB2 (DCCH)
unnamed: C26.2, R4.2, R13.1, U1.R24 (P1.06)
unnamed: C17.2, U1.B24 (XC1), Y2.1
unnamed: C18.1, U1.A23 (XC2), Y2.3
unnamed: R8.1, U2.16 (ISET)
unnamed: R12.2, U2.15 (ITERM)
unnamed: R9.2, U2.1 (TS)

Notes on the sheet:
MAIN MCU
I2C DISPLAY
JST 2 pin Battery spec: 3.7V
UCB-C CONNECTOR
BATTERY CONNECTOR
SWD Header for 1st time imaging
VBUS
IMU
layout note; refer to hardware doc for pin assignment of each cap
VDD VDD_nRF net
4.4V regulated output
1.7V - 3.6V, 1.8V typical 0.65mA active for 1.8V; estimated 0.35 for 3.3V
BATTERY CHARGER / PMIC

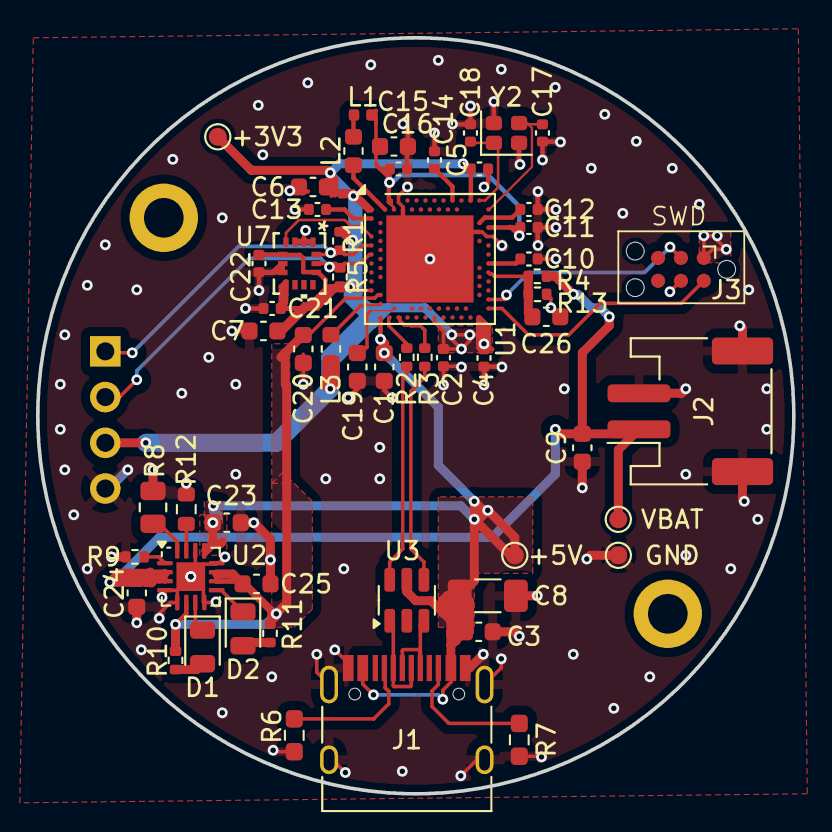
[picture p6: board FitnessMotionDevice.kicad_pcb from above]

Board: 2 copper layers, 42.0 x 42.0 mm, 57 parts (1 on the bottom side), 37 nets.

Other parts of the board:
+3V3, +5V: TestPoint_Pad_D1.0mm
GND: TestPoint_Pad_D1.0mm
VBAT: TestPoint_Pad_D1.0mm

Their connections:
+3V3: +3V3.1; also elsewhere on the board
+5V: +5V.1; also elsewhere on the board
/VBAT: VBAT.1; also elsewhere on the board
GND: GND.1; also elsewhere on the board

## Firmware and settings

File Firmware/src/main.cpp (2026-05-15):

/**
 * @file    main.cpp
 * @brief   Top-level state machine for the RepSense fitness tracker.
 *
 * States
 * ------
 *   BOOT             → init all modules, splash screen, arm wake interrupt.
 *   SLEEP            → System ON sleep, MCU at ~1.5 µA, IMU armed for wake.
 *   ACTIVE           → 200 Hz sampling, EKF, rep detect, classifier.
 *   DISPLAY_UPDATE   → triggered after a confirmed rep; partial OLED repaint.
 *
 * Transitions
 * -----------
 *   BOOT  → SLEEP                         once init done.
 *   SLEEP → ACTIVE                        on INT1 (motion-detect wake).
 *   ACTIVE → DISPLAY_UPDATE → ACTIVE      after each confirmed rep.
 *   ACTIVE → SLEEP                        after IDLE_BEFORE_SLEEP_MS
 *                                         (5 s) without motion.
 */

#include <Arduino.h>
#include "config.h"
#include "power.h"
#include "imu.h"
#include "ekf.h"
#include "rep_detector.h"
#include "exercise_classifier.h"
#include "battery.h"
#include "display.h"

// ---------------------------------------------------------------------------
// State machine
// ---------------------------------------------------------------------------
enum class State : uint8_t { Boot, Sleep, Active, DisplayUpdate };

struct Machine {
    State    state            = State::Boot;
    uint32_t lastMotionMs     = 0;
    uint32_t lastSampleUs     = 0;
    uint32_t lastDisplayReps  = UINT32_MAX;
};
static Machine sm;

// ---------------------------------------------------------------------------
// Helpers
// ---------------------------------------------------------------------------

/// @brief True if linear-accel magnitude exceeds a small motion threshold.
static bool sampleHasMotion(const ekf::Vec3 &la) {
    const float m2 = la.x*la.x + la.y*la.y + la.z*la.z;
    // ~0.5 m/s² noise floor at the wrist; below this we treat as "still".
    return m2 > (0.5f * 0.5f);
}

/// @brief Repaint the active screen with current state.
static void repaintActive() {
    display::showActive(exercise_classifier::getCommitted(),
                        (int)rep_detector::getRepCount(),
                        (int)battery::getBatteryPercent());
}

// ---------------------------------------------------------------------------
// Arduino entry points
// ---------------------------------------------------------------------------

void setup() {
#ifdef DEBUG
    Serial.begin(115200);
    // Don't block forever waiting for a host — production wrists rarely have one.
    uint32_t t0 = millis();
    while (!Serial && (millis() - t0) < 1500) {}
    Serial.println("[boot] RepSense firmware starting");
#endif

    // ----- Boot: init every module in dependency order. -----
    power::enableDCDC();
    power::configureLowPowerPeripherals();

    Wire.begin();
    Wire.setClock(I2C_FREQ);

    if (!display::begin()) {
#ifdef DEBUG
        Serial.println("[boot] display init failed");
#endif
    } else {
        display::showBootScreen();
    }

    if (!imu::begin()) {
#ifdef DEBUG
        Serial.println("[boot] imu init failed");
#endif
    }

    battery::begin();
    ekf::reset();
    rep_detector::reset();
    exercise_classifier::reset();

    // Arm IMU wake-on-motion, blank the OLED, and drop straight to sleep.
    imu::enableMotionWake();
    display::sleep();
    sm.state        = State::Sleep;
    sm.lastMotionMs = millis();
}

// ---------------------------------------------------------------------------

void loop() {
    switch (sm.state) {

    // ------------------------------------------------------------------
    case State::Sleep: {
        // Sleep until the IMU's wake interrupt fires. The CPU sits in WFE
        // at ~1.5 µA + IMU activity-detect (~25 µA) + display off (~5 µA).
        power::enterSleep();

        if (power::wakeRequested() || imu::motionDetected()) {
            power::clearWake();
            imu::clearMotionFlag();
            imu::disableMotionWake();      // switch IMU into high-perf mode
            power::restoreActivePeripherals();
            display::wake();

            // Reset filter state for a fresh session segment.
            ekf::reset();
            rep_detector::resetReps();
            exercise_classifier::reset();

            repaintActive();
            sm.state        = State::Active;
            sm.lastMotionMs = millis();
            sm.lastSampleUs = micros();
        }
        break;
    }

    // ------------------------------------------------------------------
    case State::Active: {
        // Tight 200 Hz sampling loop. We pace via micros() rather than
        // delay() so the CPU can drop to __WFE between samples for a few
        // dozen µs of leakage savings.
        const uint32_t now_us = micros();
        if ((now_us - sm.lastSampleUs) < SAMPLE_PERIOD_US) {
            __WFE();
            break;
        }
        sm.lastSampleUs += SAMPLE_PERIOD_US;

        imu::Sample s = imu::read();
        if (!s.ok) break;   // already logged in imu module under DEBUG

        ekf::step(s.gx, s.gy, s.gz, s.ax, s.ay, s.az, EKF_DT);

        const float pitch = ekf::getPitch();
        const float roll  = ekf::getRoll();
        const float yaw   = ekf::getYaw();
        const ekf::Vec3 la = ekf::getLinearAccel();

        const bool repCommitted = rep_detector::process(
            roll, pitch, yaw, s.gx, s.gy, s.gz, la.z);

        if (repCommitted) {
            (void)exercise_classifier::classify(
                rep_detector::getLastRepFeatures());
            sm.state = State::DisplayUpdate;  // fall-through next iteration
        }

        battery::update();   // throttled internally to BATTERY_SAMPLE_MS

        if (sampleHasMotion(la)) {
            sm.lastMotionMs = millis();
        } else if ((millis() - sm.lastMotionMs) >= IDLE_BEFORE_SLEEP_MS) {
            // No motion for 5 s — drop back to sleep.
            display::sleep();
            imu::enableMotionWake();
            sm.state = State::Sleep;
        }
        break;
    }

    // ------------------------------------------------------------------
    case State::DisplayUpdate: {
        // Single-shot OLED repaint after a confirmed rep, then back to ACTIVE.
        repaintActive();
        sm.state = State::Active;
        break;
    }

    // ------------------------------------------------------------------
    case State::Boot:
    default:
        // setup() handles Boot; reaching here means a bug — fall through to Sleep.
        sm.state = State::Sleep;
        break;
    }
}

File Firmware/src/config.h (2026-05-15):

/**
 * @file    config.h
 * @brief   Compile-time configuration for the RepSense fitness tracker firmware.
 *
 * All pin assignments, I2C addresses, sample rates, EKF noise covariances,
 * and rep-detector / classifier thresholds live here. Source modules must
 * never embed magic numbers — pull from this file instead.
 *
 * Target hardware: nRF52840 (Adafruit Feather pinout) + LSM6DSV IMU +
 *                  SSD1306 0.91" OLED.
 */

#ifndef REPSENSE_CONFIG_H
#define REPSENSE_CONFIG_H

#include <Arduino.h>

// ---------------------------------------------------------------------------
// Firmware identity
// ---------------------------------------------------------------------------
#define FIRMWARE_NAME       "RepSense"
#define FIRMWARE_VERSION    "0.1.0"

// ---------------------------------------------------------------------------
// I2C bus
// ---------------------------------------------------------------------------
// Arduino-nRF52 maps Pin = (port * 32) + bit. P1.04 -> 36, P1.05 -> 37, P1.06 -> 38.
constexpr uint8_t  IMU_SDA          = 36;        ///< P1.04
constexpr uint8_t  IMU_SCL          = 37;        ///< P1.05
constexpr uint8_t  IMU_INT1         = 38;        ///< P1.06
constexpr uint32_t I2C_FREQ         = 400000UL;  ///< Fast-mode I2C (400 kHz)

// ---------------------------------------------------------------------------
// Device addresses
// ---------------------------------------------------------------------------
// LSM6DSV: SA0=GND -> 7-bit 0x6A. SSD1306: 7-bit 0x3C (0x78 with R/W bit).
constexpr uint8_t IMU_ADDR          = 0x6A;
constexpr uint8_t DISPLAY_ADDR_7BIT = 0x3C;
constexpr uint8_t DISPLAY_ADDR      = 0x78;      ///< 8-bit form referenced in spec

// ---------------------------------------------------------------------------
// Battery monitor
// ---------------------------------------------------------------------------
// 1 MΩ / 1 MΩ divider feeds VBAT/2 to AIN. With internal VDD reference (3.3 V)
// and 12-bit ADC: VBAT = ADC × (2 × 3.3) / 4096 = ADC × 6.6 / 4096.
constexpr uint8_t  BATTERY_AIN          = A6;    ///< Feather VBAT pin (P0.05 / AIN3)
constexpr float    BATTERY_ADC_TO_VOLTS = 6.6f / 4096.0f;
constexpr uint32_t BATTERY_SAMPLE_MS    = 30000; ///< Sample every 30 s

// ---------------------------------------------------------------------------
// IMU sample / EKF rates
// ---------------------------------------------------------------------------
constexpr float    EKF_DT           = 0.005f;    ///< 200 Hz EKF tick (s)
constexpr uint32_t SAMPLE_PERIOD_US = 5000;      ///< 5 ms = 200 Hz

// LSM6DSV scale conversion (sensitivity at ±8 g and ±2000 dps).
constexpr float ACCEL_SENS_8G   = 0.244f * 0.001f * 9.80665f; ///< LSB -> m/s²
constexpr float GYRO_SENS_2000  = 70.0f * 0.001f * (PI / 180.0f); ///< LSB -> rad/s
constexpr float GRAVITY_MPS2    = 9.80665f;

// ---------------------------------------------------------------------------
// EKF noise covariances (tuned for wrist-worn IMU @ 200 Hz)
// ---------------------------------------------------------------------------
// Process noise (gyro integration) — small because gyro is low-noise.
constexpr float EKF_Q_GYRO      = 1.0e-5f;
// Measurement noise (accel gravity vector) — larger because wrist accel is
// contaminated by limb motion. The EKF down-weights the accel update
// dynamically when |a| ≠ g, but this is the baseline.
constexpr float EKF_R_ACCEL     = 5.0e-2f;
// Initial state covariance — large to allow fast convergence on first sample.
constexpr float EKF_P_INIT      = 1.0e-2f;

// ---------------------------------------------------------------------------
// Rep detector thresholds
// ---------------------------------------------------------------------------
constexpr uint16_t REP_WINDOW_SAMPLES   = 64;     ///< Rolling buffer length
constexpr float    REP_HPF_ALPHA        = 0.97f;  ///< High-pass filter (DC removal)
constexpr float    REP_PEAK_THRESH_DEG  = 15.0f;  ///< Min |signal| to arm peak detector
constexpr float    REP_ZERO_HYSTERESIS  = 3.0f;   ///< Deg of hysteresis around zero
constexpr uint32_t REP_MIN_DURATION_MS  = 400;    ///< Reject reps <0.4 s
constexpr uint32_t REP_MAX_DURATION_MS  = 6000;   ///< Reject reps >6.0 s
constexpr float    REP_MIN_ROM_DEG      = 25.0f;  ///< Min range-of-motion to count

// ---------------------------------------------------------------------------
// Exercise classifier — per-exercise thresholds
// ---------------------------------------------------------------------------
// (ROM in degrees, duration in ms, peak gyro in deg/s, peak linear accel in m/s²)

// BICEP_CURL
constexpr float BICEP_ROM_MIN = 80.0f, BICEP_ROM_MAX = 140.0f;
constexpr float BICEP_DUR_MIN = 1000.0f, BICEP_DUR_MAX = 3000.0f;
constexpr float BICEP_PEAK_OMEGA_MIN = 90.0f;

// SHOULDER_PRESS
constexpr float SHOULDER_ROM_MIN = 60.0f, SHOULDER_ROM_MAX = 110.0f;
constexpr float SHOULDER_DUR_MIN = 1500.0f, SHOULDER_DUR_MAX = 3500.0f;
constexpr float SHOULDER_VACCEL_MIN = 4.0f;
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
